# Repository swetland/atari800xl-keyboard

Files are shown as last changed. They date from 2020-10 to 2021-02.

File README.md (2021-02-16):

This is a work-in-progress replacement keyboard for the Atari800XL,
using Cherry MX mechanical key switches. 

- It is *not* entirely finished and production ready. 
- It has some clearance problems with the case top on the right hand side.  
- I do not have time to actively support it.

- Schematics and Layouts were done with KiCad 5.x

Parts Notes:
- A100254CT-ND (digikey) TE 2-84952-4 CONN FPC BOTTOM 24POS

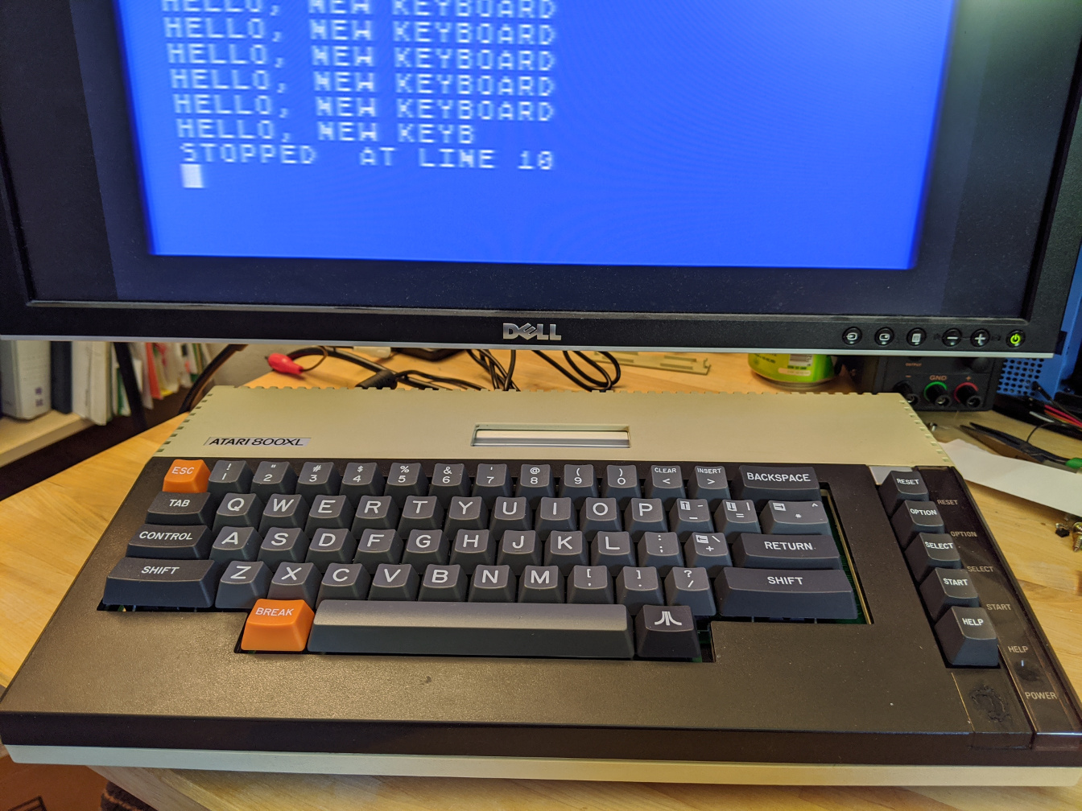
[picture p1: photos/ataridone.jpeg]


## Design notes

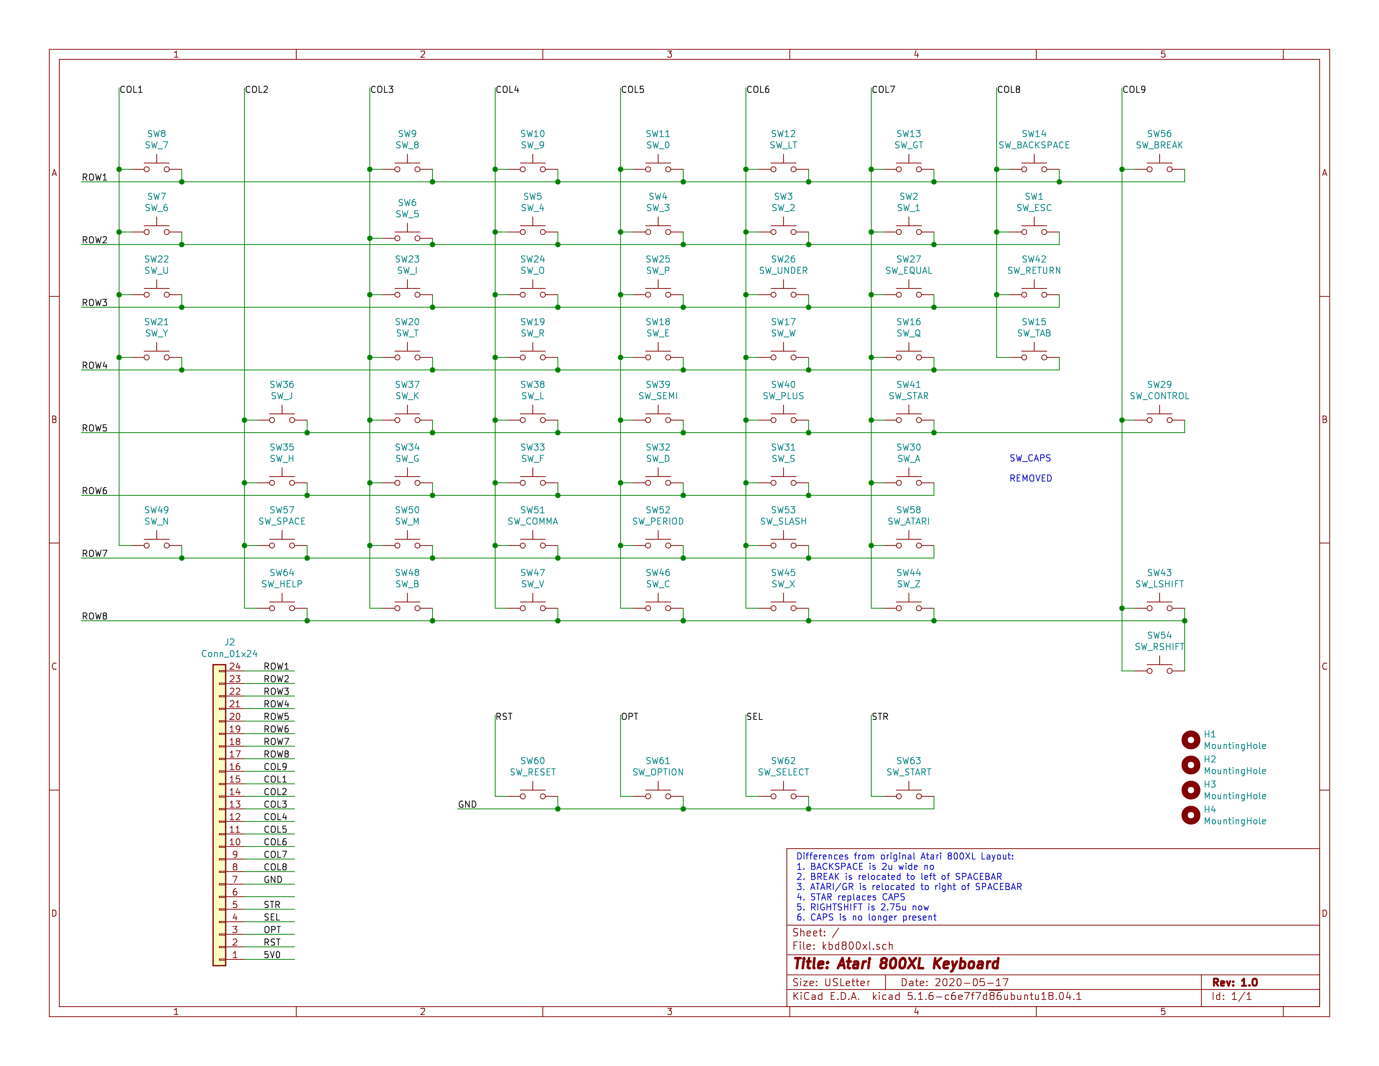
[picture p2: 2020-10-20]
keyboard/export/a800xl-kbd-v2-schematic.png

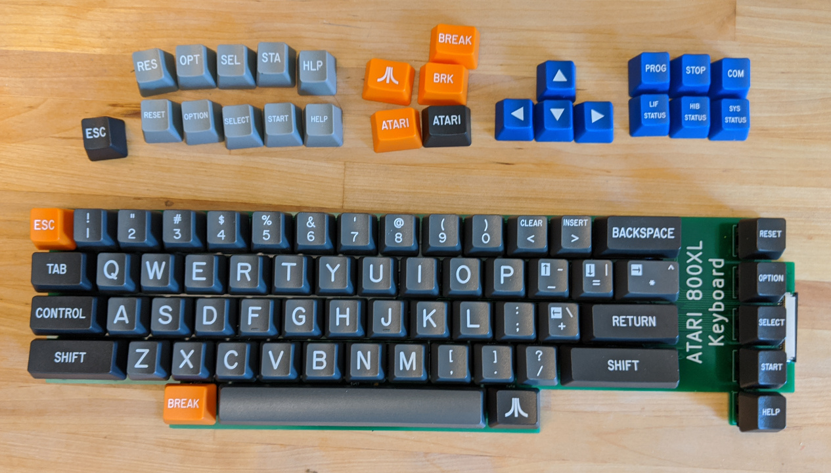
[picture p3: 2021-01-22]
photos/atarikeys.jpeg

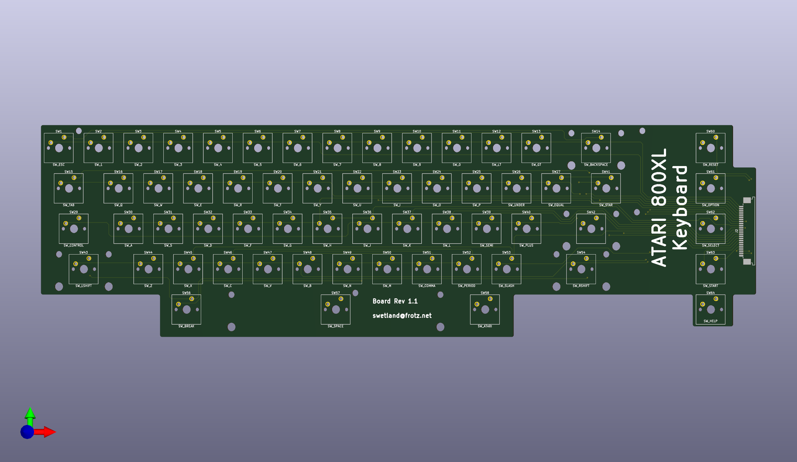
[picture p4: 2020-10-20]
keyboard/export/a800xl-v2-front.png

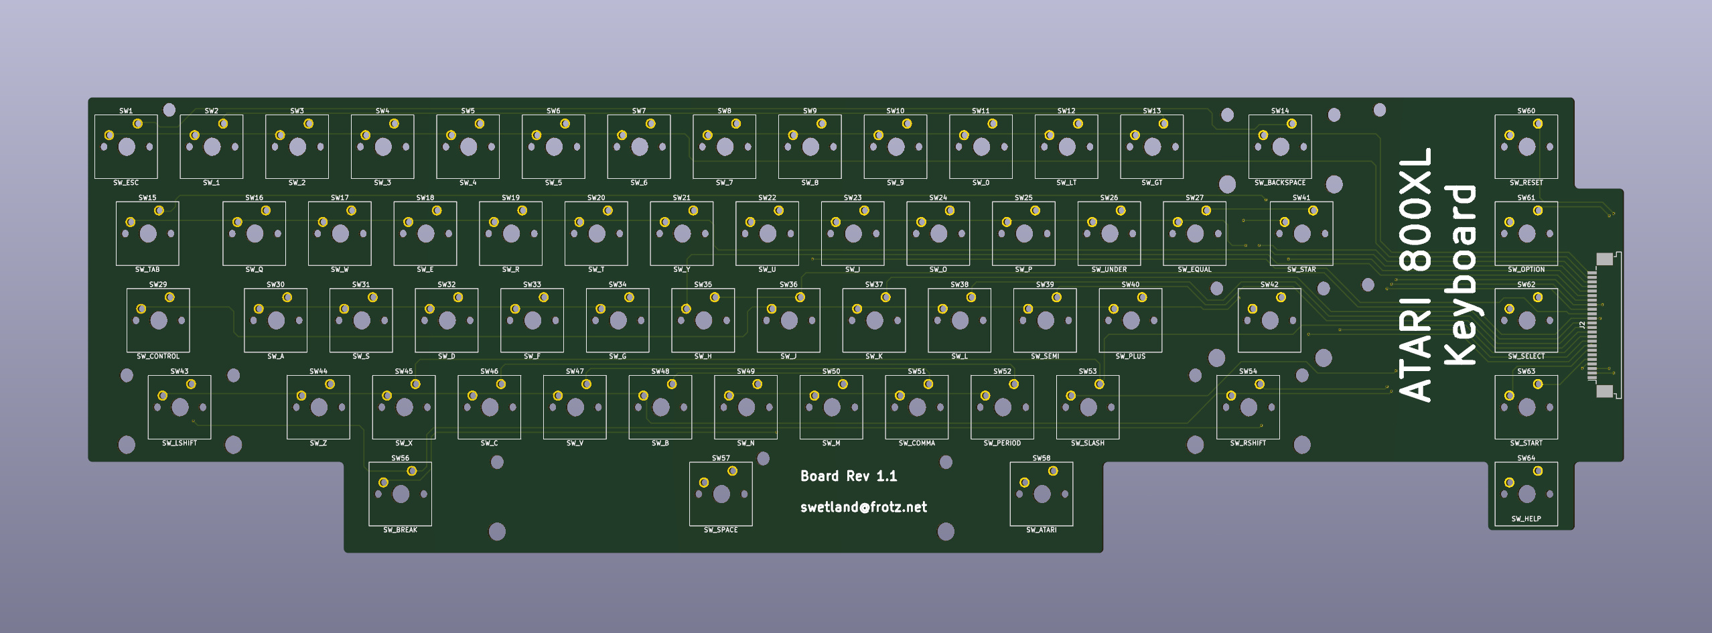
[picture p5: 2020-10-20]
keyboard/export/a800xl-v2-front.jpg

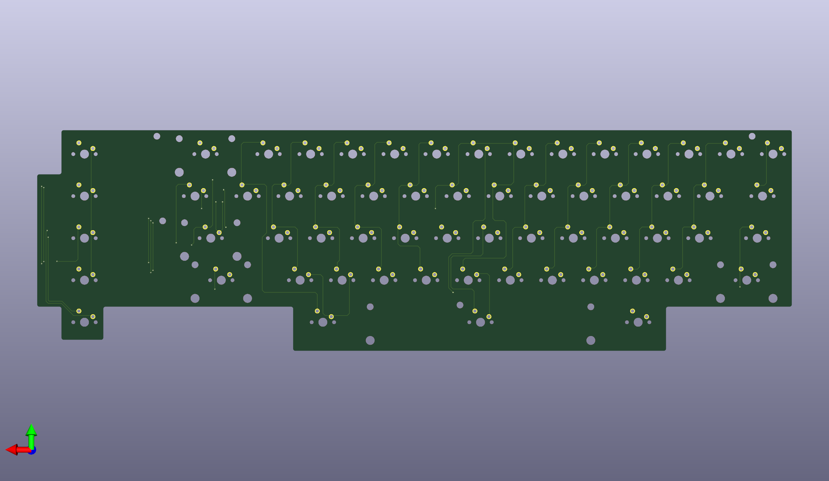
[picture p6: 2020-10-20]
keyboard/export/a800xl-v2-back.png

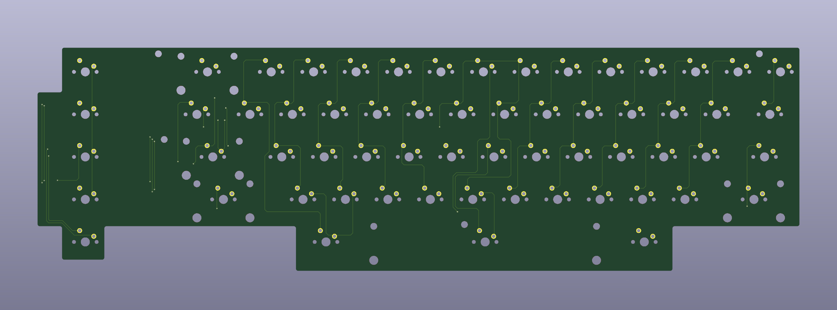
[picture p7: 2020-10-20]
keyboard/export/a800xl-v2-back.jpg

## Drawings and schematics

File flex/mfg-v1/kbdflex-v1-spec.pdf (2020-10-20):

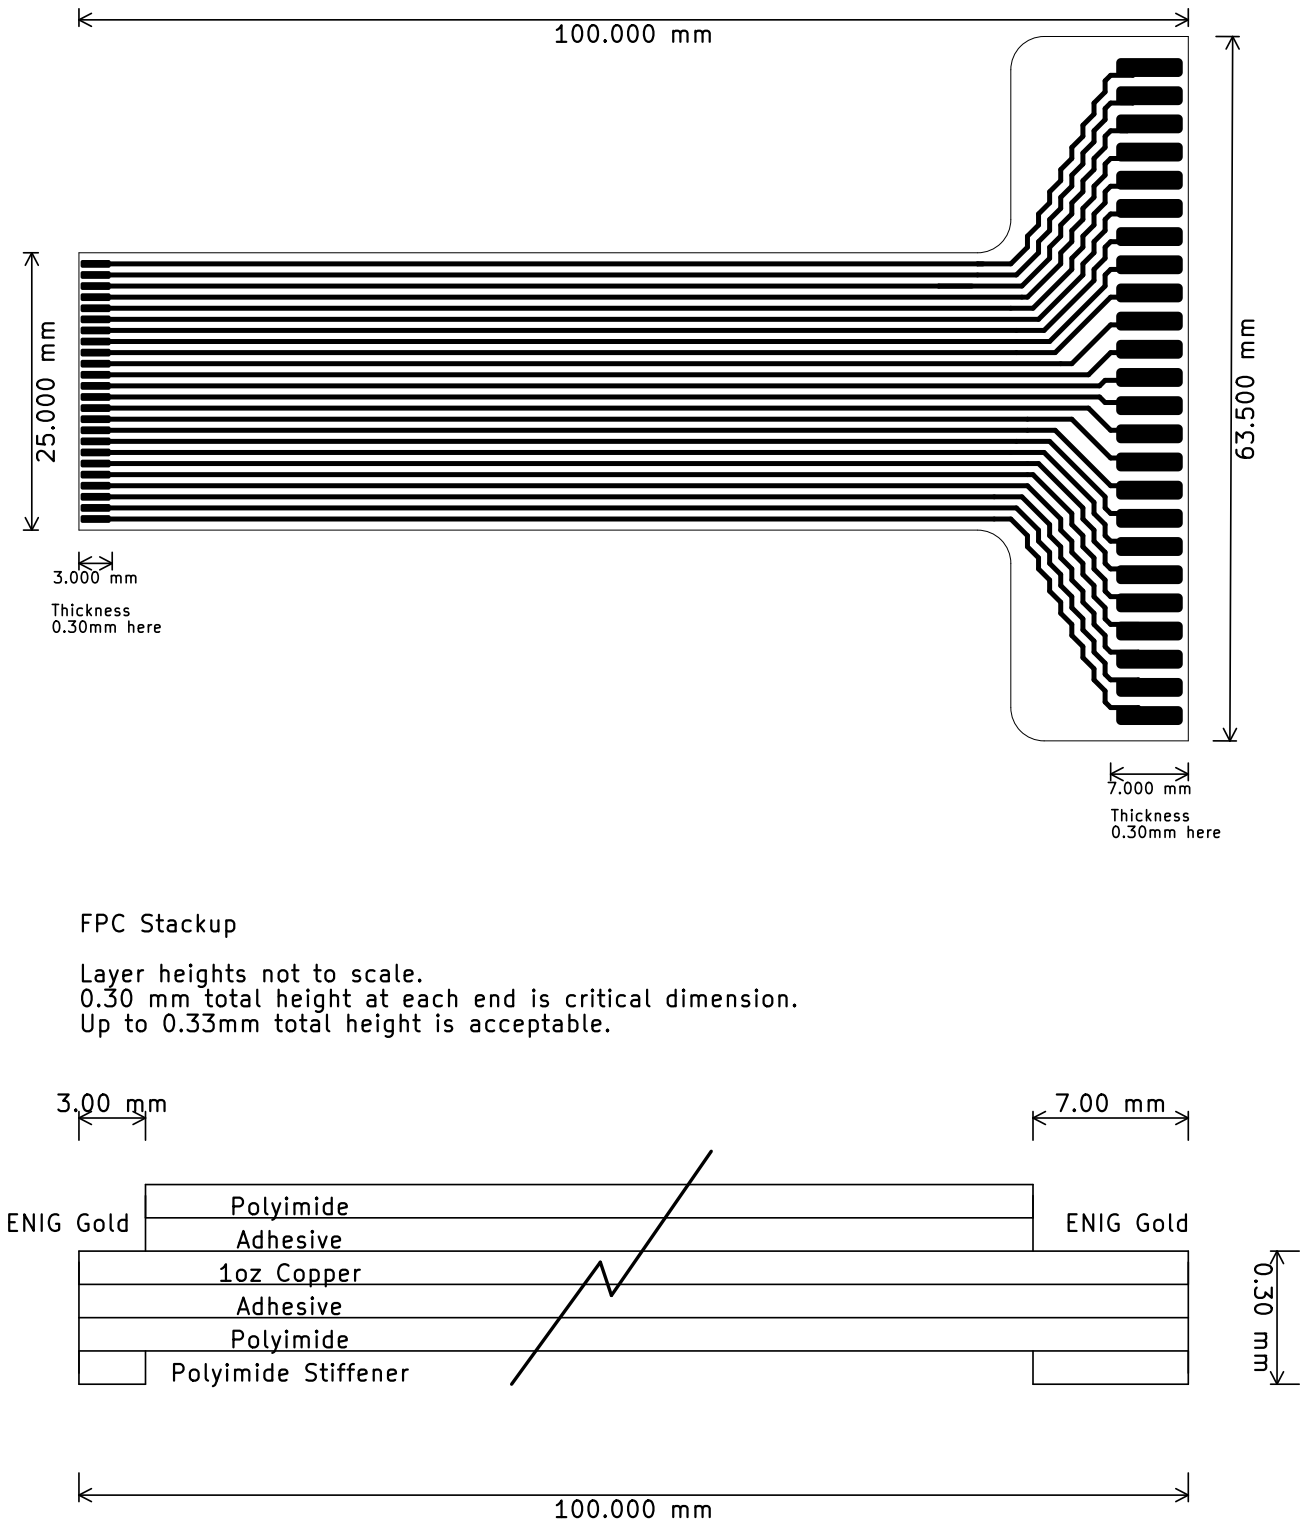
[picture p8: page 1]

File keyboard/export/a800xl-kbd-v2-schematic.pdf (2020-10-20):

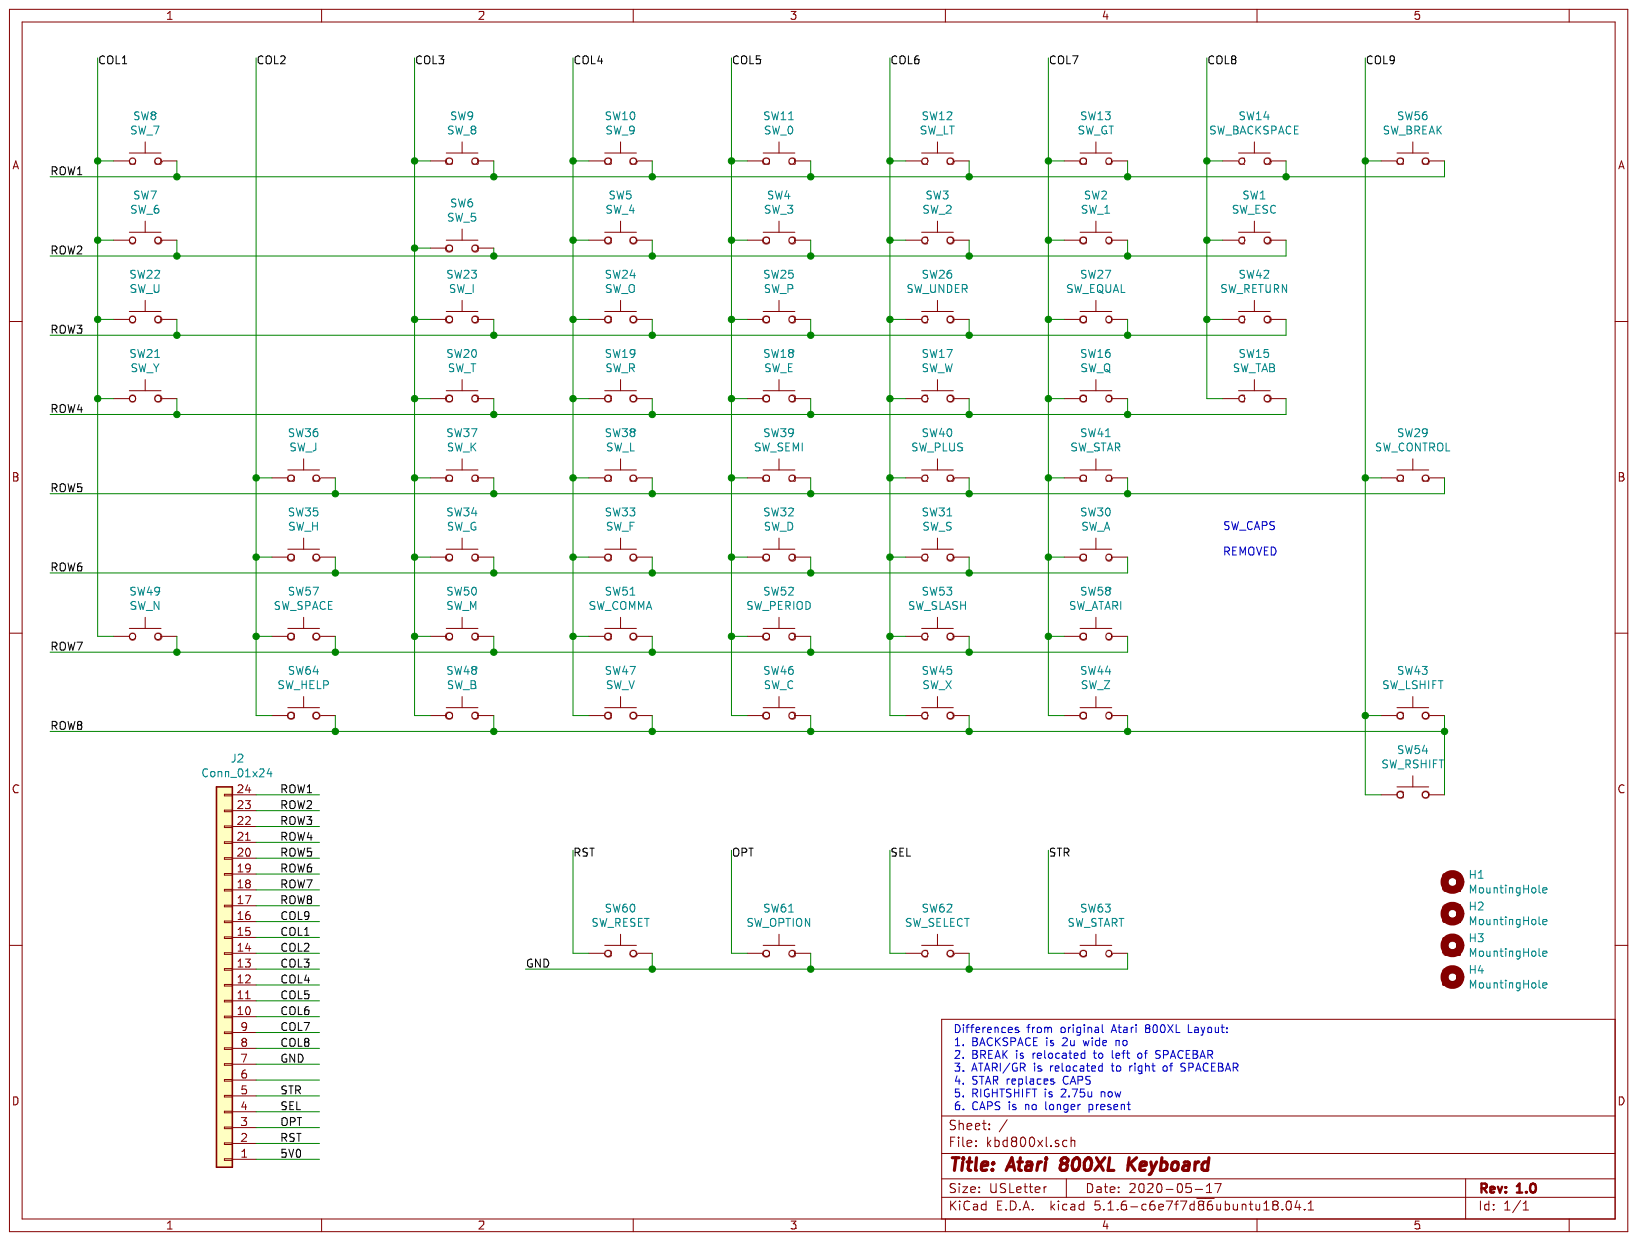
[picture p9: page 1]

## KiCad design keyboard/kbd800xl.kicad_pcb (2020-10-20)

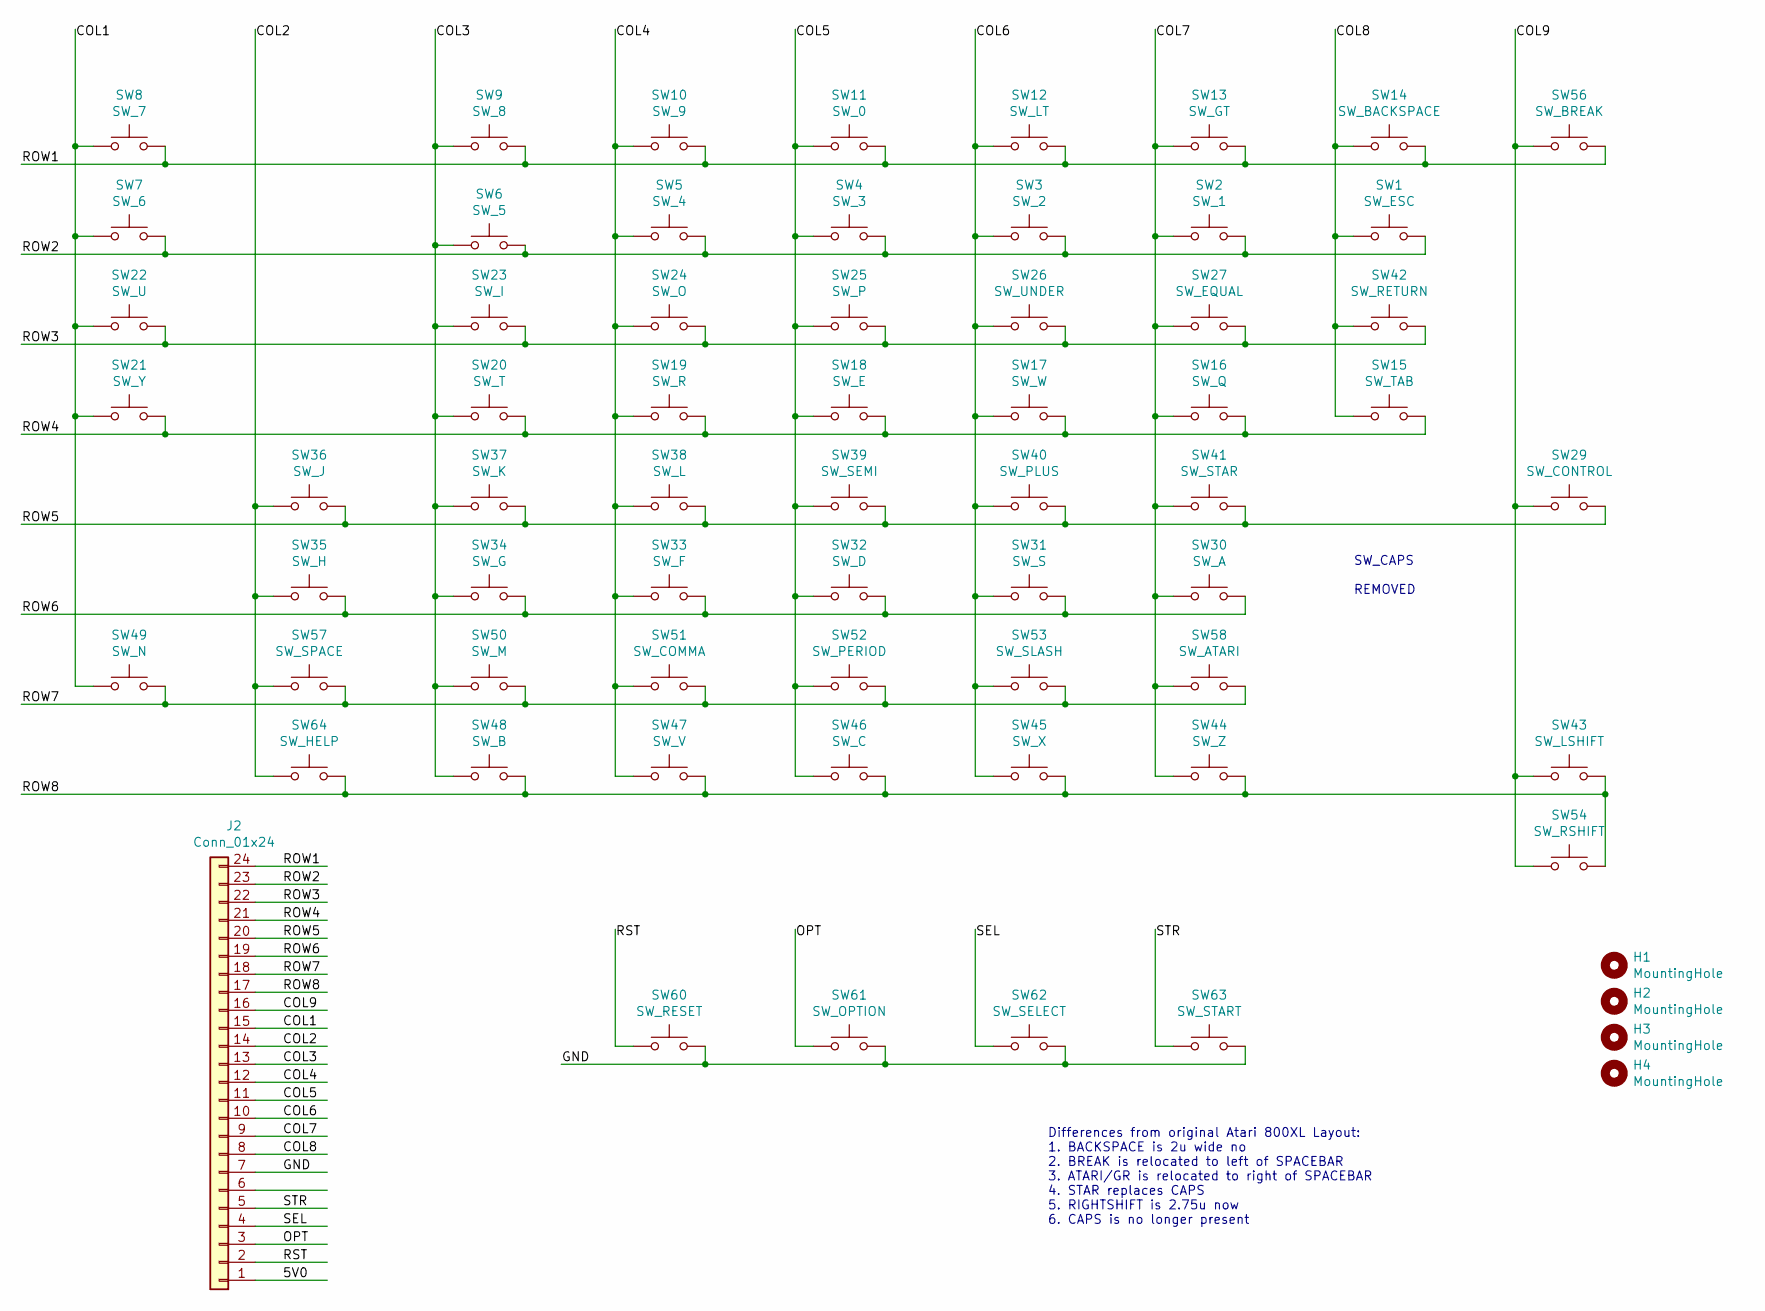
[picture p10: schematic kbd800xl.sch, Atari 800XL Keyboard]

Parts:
H1, H2, H3, H4: MountingHole; MountingHole_3mm
J2: Conn_01x24; TE_2-84952-4_1x24-1MP_P1.0mm_Horizontal
SW1: SW_ESC; SW_Cherry_MX_1.00u_PCB
SW2: SW_1; SW_Cherry_MX_1.00u_PCB
SW3: SW_2; SW_Cherry_MX_1.00u_PCB
SW4: SW_3; SW_Cherry_MX_1.00u_PCB
SW5: SW_4; SW_Cherry_MX_1.00u_PCB
SW6: SW_5; SW_Cherry_MX_1.00u_PCB
SW7: SW_6; SW_Cherry_MX_1.00u_PCB
SW8: SW_7; SW_Cherry_MX_1.00u_PCB
SW9: SW_8; SW_Cherry_MX_1.00u_PCB
SW10: SW_9; SW_Cherry_MX_1.00u_PCB
SW11: SW_0; SW_Cherry_MX_1.00u_PCB
SW12: SW_LT; SW_Cherry_MX_1.00u_PCB
SW13: SW_GT; SW_Cherry_MX_1.00u_PCB
SW14: SW_BACKSPACE; SW_Cherry_MX_2.00u_PCB
SW15: SW_TAB; SW_Cherry_MX_1.50u_PCB
SW16: SW_Q; SW_Cherry_MX_1.00u_PCB
SW17: SW_W; SW_Cherry_MX_1.00u_PCB
SW18: SW_E; SW_Cherry_MX_1.00u_PCB
SW19: SW_R; SW_Cherry_MX_1.00u_PCB
SW20: SW_T; SW_Cherry_MX_1.00u_PCB
SW21: SW_Y; SW_Cherry_MX_1.00u_PCB
SW22: SW_U; SW_Cherry_MX_1.00u_PCB
SW23: SW_I; SW_Cherry_MX_1.00u_PCB
SW24: SW_O; SW_Cherry_MX_1.00u_PCB
SW25: SW_P; SW_Cherry_MX_1.00u_PCB
SW26: SW_UNDER; SW_Cherry_MX_1.00u_PCB
SW27: SW_EQUAL; SW_Cherry_MX_1.00u_PCB
SW29: SW_CONTROL; SW_Cherry_MX_1.75u_PCB
SW30: SW_A; SW_Cherry_MX_1.00u_PCB
SW31: SW_S; SW_Cherry_MX_1.00u_PCB
SW32: SW_D; SW_Cherry_MX_1.00u_PCB
SW33: SW_F; SW_Cherry_MX_1.00u_PCB
SW34: SW_G; SW_Cherry_MX_1.00u_PCB
SW35: SW_H; SW_Cherry_MX_1.00u_PCB
SW36: SW_J; SW_Cherry_MX_1.00u_PCB
SW37: SW_K; SW_Cherry_MX_1.00u_PCB
SW38: SW_L; SW_Cherry_MX_1.00u_PCB
SW39: SW_SEMI; SW_Cherry_MX_1.00u_PCB
SW40: SW_PLUS; SW_Cherry_MX_1.00u_PCB
SW41: SW_STAR; SW_Cherry_MX_1.50u_PCB
SW42: SW_RETURN; SW_Cherry_MX_2.25u_PCB
SW43: SW_LSHIFT; SW_Cherry_MX_2.25u_PCB
SW44: SW_Z; SW_Cherry_MX_1.00u_PCB
SW45: SW_X; SW_Cherry_MX_1.00u_PCB
SW46: SW_C; SW_Cherry_MX_1.00u_PCB
SW47: SW_V; SW_Cherry_MX_1.00u_PCB
SW48: SW_B; SW_Cherry_MX_1.00u_PCB
SW49: SW_N; SW_Cherry_MX_1.00u_PCB
SW50: SW_M; SW_Cherry_MX_1.00u_PCB
SW51: SW_COMMA; SW_Cherry_MX_1.00u_PCB
SW52: SW_PERIOD; SW_Cherry_MX_1.00u_PCB
SW53: SW_SLASH; SW_Cherry_MX_1.00u_PCB
SW54: SW_RSHIFT; SW_Cherry_MX_2.75u_PCB
SW56: SW_BREAK; SW_Cherry_MX_1.25u_PCB
SW57: SW_SPACE; SW_Cherry_MX_6.25u_PCB
SW58: SW_ATARI; SW_Cherry_MX_1.25u_PCB
SW60: SW_RESET; SW_Cherry_MX_1.00u_PCB
SW61: SW_OPTION; SW_Cherry_MX_1.00u_PCB
SW62: SW_SELECT; SW_Cherry_MX_1.00u_PCB
SW63: SW_START; SW_Cherry_MX_1.00u_PCB
SW64: SW_HELP; SW_Cherry_MX_1.00u_PCB

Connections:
/5V0: J2.1
/COL1: J2.15, SW7.1, SW8.1, SW21.1, SW22.1, SW49.1
/COL2: J2.14, SW35.1, SW36.1, SW57.1, SW64.1
/COL3: J2.13, SW6.1, SW9.1, SW20.1, SW23.1, SW34.1, SW37.1, SW48.1, SW50.1
/COL4: J2.12, SW5.1, SW10.1, SW19.1, SW24.1, SW33.1, SW38.1, SW47.1, SW51.1
/COL5: J2.11, SW4.1, SW11.1, SW18.1, SW25.1, SW32.1, SW39.1, SW46.1, SW52.1
/COL6: J2.10, SW3.1, SW12.1, SW17.1, SW26.1, SW31.1, SW40.1, SW45.1, SW53.1
/COL7: J2.9, SW2.1, SW13.1, SW16.1, SW27.1, SW30.1, SW41.1, SW44.1, SW58.1
/COL8: J2.8, SW1.1, SW14.1, SW15.1, SW42.1
/COL9: J2.16, SW29.1, SW43.1, SW54.1, SW56.1
/GND: J2.7, SW60.2, SW61.2, SW62.2, SW63.2
/OPT: J2.3, SW61.1
/ROW1: J2.24, SW8.2, SW9.2, SW10.2, SW11.2, SW12.2, SW13.2, SW14.2, SW56.2
/ROW2: J2.23, SW1.2, SW2.2, SW3.2, SW4.2, SW5.2, SW6.2, SW7.2
/ROW3: J2.22, SW22.2, SW23.2, SW24.2, SW25.2, SW26.2, SW27.2, SW42.2
/ROW4: J2.21, SW15.2, SW16.2, SW17.2, SW18.2, SW19.2, SW20.2, SW21.2
/ROW5: J2.20, SW29.2, SW36.2, SW37.2, SW38.2, SW39.2, SW40.2, SW41.2
/ROW6: J2.19, SW30.2, SW31.2, SW32.2, SW33.2, SW34.2, SW35.2
/ROW7: J2.18, SW49.2, SW50.2, SW51.2, SW52.2, SW53.2, SW57.2, SW58.2
/ROW8: J2.17, SW43.2, SW44.2, SW45.2, SW46.2, SW47.2, SW48.2, SW54.2, SW64.2
/RST: J2.2, SW60.1
/SEL: J2.4, SW62.1
/STR: J2.5, SW63.1

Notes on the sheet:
Differences from original Atari 800XL Layout: 1. BACKSPACE is 2u wide no 2. BREAK is relocated to left of SPACEBAR 3. ATARI/GR is relocated to right of SPACEBAR 4. STAR replaces CAPS 5. RIGHTSHIFT is 2.75u now 6. CAPS is no longer present
SW_CAPS REMOVED

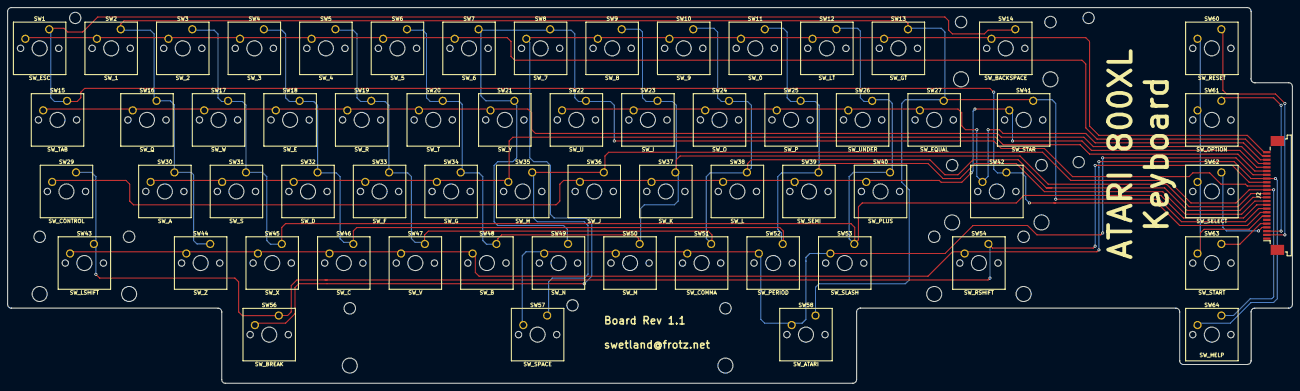
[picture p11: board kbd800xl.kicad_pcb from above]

Board: 2 copper layers, 342.0 x 100.0 mm, 66 parts (0 on the bottom side), 22 nets.

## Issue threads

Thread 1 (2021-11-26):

PCB mounting?

wildstar87, 2021-11-26:
How did you mount the Keyboard PCB to the top case?  I noticed that you were doing some measuring against the stackpole plate.  Unless you modified the existing plate, did you come up with another method?

swetland, 2021-11-26:
I tried to line some holes in the PCB up with the backplate, with mixed success (due to inaccuracies in my measurements or limited clearance around the key switches).  What I ended up doing was putting down a couple layers of non-conductive gaffer's tape on the top of the plate (to prevent the pins of the key switches from shorting against the plate), secured the keyboard to the plate with one or two small nylon screws, and called it "good enough" for a prototype.

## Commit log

2020-10-20 initial checkin of keyboard kicad project
    [kbd800xl-B_Cu.gbl, kbd800xl-B_Mask.gbs, kbd800xl-B_Paste.gbp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]
2020-10-20 initial checkin of flex connector kicad project
    [kbdflex.kicad_pcb, kbdflex.sch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]
